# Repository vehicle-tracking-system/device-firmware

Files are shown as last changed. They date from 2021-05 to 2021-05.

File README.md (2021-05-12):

# Tracker for vehicle tracking system

This repository is part of project for tracking vehicles. Main repository with backend server can be
found [here](https://gitlab.fit.cvut.cz/jehlima2/vehicle-tracking-system).

## Configuration

Whole configuration is located in `Constants.h` header file. Default configuration should look like:

```cpp
const int MPU_ADDR = 0x69;
static const int MOVEMENT_THRESHOLD = 3000;

static const int POWER_PIN = 5;

static const int RED_LED_PIN = 26;
static const int GREEN_LED_PIN = 25;

static const int POSITION_FREQUENCE = 3000; // ms
static const int POSITIONS_IN_REPORT = 5;
static const int REPORT_FREQUENCE = POSITIONS_IN_REPORT * POSITION_FREQUENCE; // ms

static char WIFI_SSID[] = "tracker";
static char WIFI_PASSWORD[] = "12345678";

static char STATIC_FILES_PREFIX[] = "/w";
static int HTTP_PORT = 80;
static int DNS_PORT = 53;
static char WEBSOCKET_PATH[] = "/ws";

static float MINIMAL_ACCURACY = 3.0;
static float SPEED_LOWER_LIMIT = 3.0;
static float SPEED_UPPER_LIMIT = 200.0;
```

Variable name | Description
--- | --- 
MPU_ADDR | I2C address of accelerometer
POWER_PIN | ESP32 pin that is connected to power pin on WARCAR module
RED_LED_PIN | Pin that is connected to red (part of) LED
GREEN_LED_PIN | Pin that is connected to green (part of) LED
POSITION_FREQUENCE | sampling frequency of actual vehicle position
REPORT_FREQUENCE | frequency of sending reports to the MQTT broker
MAX_DISTANCE_BETWEEN_TWO_POSITIONS | positions that are set apart that are more than this threshold (in meters) apart are ignored as invalid
WIFI_SSID | name of the wifi network broadcast by the tracker
WIFI_PASSWORD | password to the wifi network broadcast by the tracker
STATIC_FILES_PREFIX | path to frontend in SPIFFS (other) filesystem
HTTP_PORT | number of port where the web ui will be exposed
WEBSOCKET_PATH | path to endpoint where it will be possible to connect
MINIMAL_ACCURACY | data from GPS with lower accuracy then this threshold will be ignored
SPEED_LOWER_LIMIT | data from GPS with lower speed then this threshold will be ignored
SPEED_UPPER_LIMIT | data from GPS with higher speed then this threshold will be ignored

Variables above allows to modify just technical aspects of tracker. The configuration and pairing with backend is done
by the UI. This is the reason why tracker needs to configure WiFi SSID and password. Connect to WiFi broadcast by
tracker (`WIFI_SSID`). Once you will be connected, you can type `tracker.local` into address line in your browser. User
interface will appear and you'll be prompted to upload configuration file. You can generate a configuration file in the
web administration (more info here: *TO DO*).

## Build

A `PlatformIO` framework is required for the code to work properly!

There is `upload-all.sh` build script that compile whole code and uploads it to ESP (ports can be changed
in `platformio.ini`)

## Wiring

Wiring

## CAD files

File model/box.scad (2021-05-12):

DEBUG = false;

board_size = [1.5, 50, 80];
esp_size = [5, 51.8, 28.5];
hole_dia = 2;
inner_box = [45, 55, 82];
fatness = 3.6;
cable_hole_radius = 3.5;
cover_overlay = 10;
bottom_size = inner_box.z / 2 ;
top_size = inner_box.z - bottom_size;
board_thickens = 1.5;
rail_size = board_thickens + 0.2;
rail_thicknes = 1;
round_prec = 40;
led_hole_radius = 5.2;
acc_hole = 2.8;
power_hole_radius = 6;

echo("Box side thicknes ", fatness / 2);

module Board(x, y, z) {
    translate([x, y, z]) union() {
        color("black") cube(board_size);
    }
}

module ESP(x, y, z) {
    translate([x, y, z]) union() {
        color("black") cube(esp_size);
    }
}

module SideRail(x, y, z, length) {
    color("blue") translate([x, y, z]) difference() {
        cube([(rail_size * 2), rail_thicknes, length]);
        translate([rail_size / 2, 0, 0]) {
            cube([rail_size + .01, rail_thicknes + 0.1, length + 0.1]);
        }
    }
}

module BottomRail(x, y, z, length) {
    color("red") translate([x, y, z]) difference() {
        cube([(rail_size * 2), 5, length]);
        translate([rail_size / 2, 0, 0]) {
            cube([rail_size + .01, 5 + 0.1, length + 0.1]);
        }
    }
}

module PowerHole(x, y, z) {
    color("blue") rotate([0, 0, 0]) translate([x, y, z]) {
        cylinder(h = fatness + .02, d = power_hole_radius, $fn = round_prec);
    }
}

module LedHole(x, y, z) {
    color("blue") rotate([90, 0, 90]) translate([y, z, x]) {
        cylinder(h = fatness + .02, d = led_hole_radius, $fn = round_prec);
    }
}


module CableHole(x, y, z) {
    color("blue") rotate([90, 0, 90]) translate([y - fatness, z, x]) {
        translate([- cable_hole_radius / 2, 0, 0]) cube([cable_hole_radius, 100, fatness + .02]);
        cylinder(h = fatness + .02, d = cable_hole_radius, $fn = round_prec);
    }
}

module Bottom(x, y, z) {
    translate([x, y, z]) {
        difference() {
            union() {
                size = [inner_box.x + fatness, inner_box.y + fatness, (bottom_size + (fatness / 2))];
                cube(size);
                echo("Bottom size ", size);
                echo("Bottom overlay thicknes", (fatness / 2) - (fatness / 4));
                color("purple") translate([fatness / 4, fatness / 4, bottom_size + (fatness / 2)]) {
                    size = [inner_box.x + 2 * (fatness / 4), inner_box.y + 2 * (fatness / 4), cover_overlay];
                    echo("Bottom overlay ", size);
                    echo("Top overlay thicknes ", (fatness / 2) - (fatness / 4));
                    cube(size);
                }
            }
            translate([fatness / 2, fatness / 2, fatness / 2]) {
                color("gray") cube([inner_box.x, inner_box.y, bottom_size + 100]);
            }
            CableHole(inner_box.x + fatness / 2 - .01, inner_box.y - 7, 40);
            LedHole(inner_box.x + fatness / 2 - .01, fatness / 2 + inner_box.y / 2, 40);
            PowerHole(fatness / 2 + inner_box.x / 2, fatness / 2 + inner_box.y / 2, 0 - .01);
        }

        color("green") union() {
            translate([((inner_box.x / 5) - rail_size / 2), fatness / 2, fatness]) cube([rail_size * 2, 2.01,
                bottom_size]);
            SideRail(((inner_box.x / 5) - rail_size / 2), ((fatness / 2) + 2) - .01, z + fatness, bottom_size +
                .01)
            ;
            translate([(inner_box.x / 5) - rail_size / 2, (fatness / 2), fatness / 2]) cube([rail_size * 2, 12, 2]);
            rotate([90, 0, 0]) BottomRail(x + (inner_box.x / 5) - rail_size / 2, fatness / 2 - .01 + 2, - (12 + fatness
                / 2)
            , 12);
        }

        color("green") union() {
            translate([((inner_box.x / 5) - rail_size / 2), ((fatness / 2) + inner_box.y) - 3, fatness / 2 + 2])
                cube([rail_size * 2, 3.01, 7]);
            SideRail(((inner_box.x / 5) - rail_size / 2), (fatness / 2 + inner_box.y) - rail_thicknes - 3, z +
                    fatness / 2 + 7 - .01, 2);
            translate([(inner_box.x / 5) - rail_size / 2, (inner_box.y + fatness / 2) - 12, fatness / 2]) cube([
                    rail_size * 2, 12, 2]);
            rotate([90, 0, 0]) BottomRail((inner_box.x / 5) - rail_size / 2, fatness / 2 - .01 + 2, - (inner_box.y +
                    fatness / 2), 12);
        }


        color("pink") translate([(inner_box.x / 10) + 32, .01, fatness / 2]) cube([1, inner_box.y + fatness - .02, 33]);
        translate([inner_box.x - 15, fatness / 2 + 3, fatness / 2 - .01]) {
            roof_len = 22;
            acc_space = (roof_len - 15) / 2;
            echo("Acc space ", acc_space)
            color("white") translate([0, 0, 0]) {
                union() {
                    cylinder(h = 3, d = acc_hole, $fn = round_prec);
                    translate([0, 15, 0]) cylinder(h = 3, d = acc_hole, $fn = round_prec);
                }
            };
        }
        if (DEBUG) Board((inner_box.x / 5), fatness / 2 + 2, fatness / 2);
    }
}

module Cover(x, y, z) {
    translate([x, y, z]) {
        union() {
            difference() {
                size = [inner_box.x + fatness, inner_box.y + fatness, (top_size + (fatness / 2))];
                echo("Top size ", size);
                cube(size);
                translate([fatness / 2, fatness / 2, fatness / 2]) {
                    color("gray") cube([inner_box.x, inner_box.y, top_size + 100]);
                }
                taper_start = top_size - cover_overlay + fatness / 2 + .01;
                echo("Lower edge of taper ", taper_start, " taper height ", top_size - taper_start);
                translate([fatness / 4 - .1, fatness / 4 - .1, taper_start]) {
                    size = [inner_box.x + 2 * (fatness / 4 + .1), inner_box.y + 2 * (fatness / 4 + .1), cover_overlay];
                    echo("Top overlay thicknes ", size);
                    echo("Top overlay thicknes ", (fatness / 2) - (fatness / 4 - .1));
                    color("purple") cube(size);
                }
            }
        }
    }
}


Bottom(0, 0, 0);
Cover(100, 0, 0);
if (DEBUG) ESP(fatness / 2 + 40, (inner_box.y - esp_size.y) / 2, fatness / 2);

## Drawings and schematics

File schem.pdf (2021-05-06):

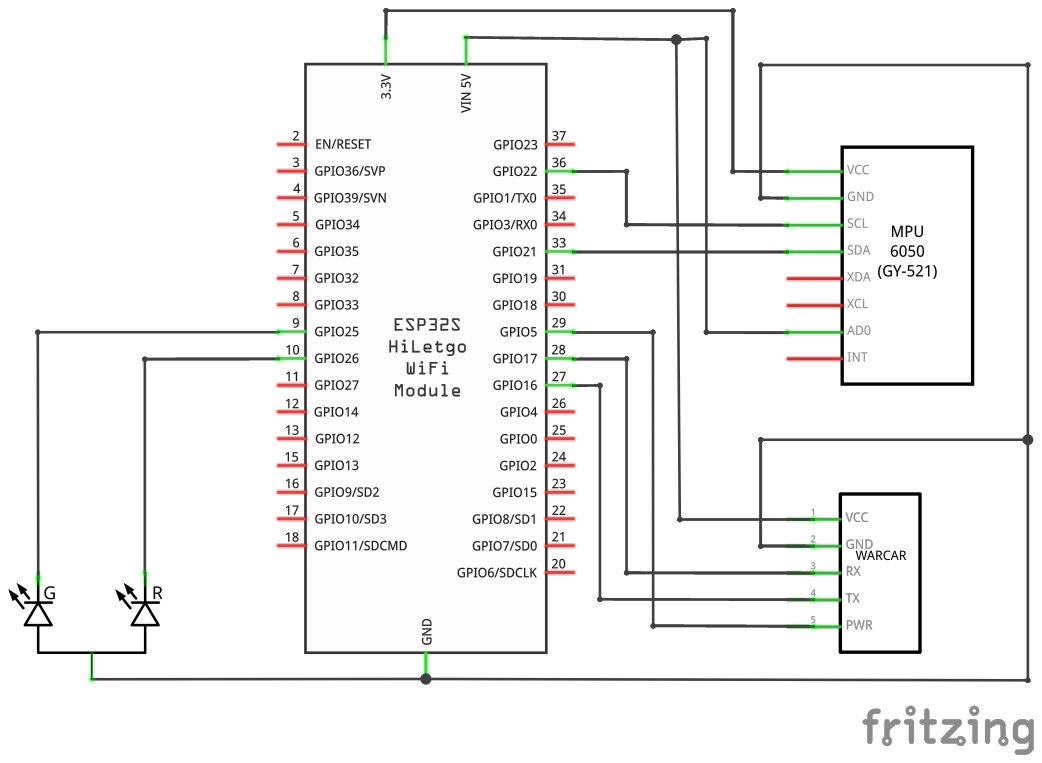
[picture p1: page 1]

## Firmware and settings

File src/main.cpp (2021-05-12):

#include <Arduino.h>

#include <Preferences.h>
#include "Constants.h"
#include <logic/StateManager.h>
#include <logic/GSM.h>
#include <networking/WebServer.h>
#include <networking/AP.h>
#include <networking/WifiClient.h>
#include <logic/LedController.h>
#include <logic/Accelerometer.h>

Preferences preferences;
StateManager stateManager(preferences);
Accelerometer accelerometer(stateManager);
LedController ledController(stateManager);
GSM gsm(stateManager);
WebServer webServer;
JsonConnector jsonConnector;

long counter = 0;

// return in setup function can stop all tasks run from there!
void setup() {
    Serial.begin(115200);
    if (!FileSystem.begin()) {
        ERROR_PRINT("Could not init FS\n", NULL);
    }
    DEBUG_PRINT("Initializing...\n", NULL);
    DEBUG_PRINT("Max distance between two positions is %f\n", MAX_DISTANCE_BETWEEN_TWO_POSITIONS);
    preferences.begin("tracker", false);
    stateManager.begin();

#ifdef USE_ACCELEROMETER
    if (!accelerometer.begin()) {
        ERROR_PRINT("Accelerometer init failed!", NULL);
        stateManager.setError("Accelerometer init failed!");
    }

    DefaultTasker.loopEvery("acc", 50, [] {
        if (!accelerometer.updateAcceleration()) {
            ERROR_PRINT("Update acceleration failed\n", NULL);
        }
//        Serial.printf("%ld,%f\n", counter, stateManager.getAcc());
        counter++;
    });
#endif

    // start webserver
    NetworkTasker.once("ap-server", [] {
#ifdef WIFI_MODE
        WifiClient::begin(WIFI_MODE_SSID, WIFI_MODE_PASS);
#else
        String ssid = WIFI_SSID + WiFi.macAddress();
        DEBUG_PRINT("SSID: %s\n", ssid.c_str());
        AP::begin(ssid.c_str(), WIFI_PASSWORD);
#endif
        webServer.begin(jsonConnector);
    });

#ifndef WIFI_MODE
    // turn off wifi AP and webserver after timeout
    NetworkTasker.once("ap-off", [] {
#ifdef AP_AUTO_OFF
        DEBUG_PRINT("Registering promise to turn off AP...\n", NULL);
        Tasker::sleep(120000);
        DEBUG_PRINT("Turning off AP...\n", NULL);
        AP::stop();
        webServer.stop();
#endif
    });
#endif


    jsonConnector.subscribe([](const JsonDocument &json) {
        DEBUG_PRINT("Configuration JSON received\n", NULL);
        if (json["type"].as<String>() == "file") {
            preferences.putString("token", json["token"].as<char *>());
            preferences.putLong("vehicleId", json["vehicleId"].as<long>());
            preferences.putString("mqttHost", json["mqttHost"].as<String>());
            preferences.putString("mqttTopic", json["mqttTopic"].as<String>());
            preferences.putInt("mqttPort", json["mqttPort"].as<int>());
            preferences.putString("mqttUsername", json["mqttUsername"].as<String>());
            preferences.putString("mqttPassword", json["mqttPassword"].as<String>());
        }
        if (json["type"].as<String>() == "form") {
            preferences.putString("apnHost", json["apnHost"].as<String>());
            preferences.putString("apnUser", json["apnUser"].as<String>());
            preferences.putString("apnPass", json["apnPass"].as<String>());
        }
        stateManager.setTextState("Configuration updated...");
    });

    NetworkTasker.loopEvery("state", 100, [] {
        if (stateManager.stateToSend()) {
            DynamicJsonDocument doc(2048);
            doc["state"] = stateManager.textState() + " " + stateManager.getAcc();
            doc["new"] = stateManager.stateToSend();
            doc["latitude"] = stateManager.lat();
            doc["longitude"] = stateManager.lng();
            doc["speed"] = stateManager.speed();
            doc["isMoving"] = stateManager.moving();
            jsonConnector.send(doc);
        }
    });

    if (!gsm.begin()) {
        ERROR_PRINT("GSM initialization failed! Check wiring and reset.\n", NULL);
        return;
    }

    DEBUG_PRINT("Starting the app...\n", NULL);

    // read new position to buffer from GPS
    DefaultTasker.loopEvery("get-position", POSITION_FREQUENCE, [] {
        gsm.enqueueNewPosition();
    });

    // send report with positions to MQTT broker
    DefaultTasker.loopEvery("send-report", REPORT_FREQUENCE, [] {
        if (!gsm.sendReport()) {
            ERROR_PRINT("Send report failed!!!\n", NULL);
        }
    });

    DEBUG_PRINT("Startup finished!\n", NULL);

}

void loop() {
    // no op - everything is handled by native tasks through Tasker
}

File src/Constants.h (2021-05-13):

#ifndef TRACKER_CONSTANTS_H
#define TRACKER_CONSTANTS_H

#include <FS.h>
#include <SPIFFS.h>

#include "../lib/Tasker/Tasker.h"

//
// MESSAGE LEVELS
//
#define DEBUG
#define ERROR
////

#define TINY_GSM_MODEM_SIM808
//#define TINY_GSM_DEBUG Serial // UNCOMMENT THIS FOR SHOW DEBUG LOGS IN SERIAL
#define SERIALGSM Serial2

#ifdef DEBUG
#define DEBUG_PRINT(x, ...)  Serial.print("[DBG] "); Serial.printf(x, __VA_ARGS__)
#else
#define DEBUG_PRINT(x, ...)
#endif

#ifdef ERROR
#define ERROR_PRINT(x, ...)  Serial.print("[ERR] "); Serial.printf(x, __VA_ARGS__)
#else
#define ERROR_PRINT(x, ...)
#endif

#define AP_AUTO_OFF
#define USE_ACCELEROMETER // IF DEFINED, TRACKER RECOGNIZE MOVEMENT USING ACCELEROMETER
//#define WIFI_MODE // IF DEFINED, TRACKER CONNECT YOURSELF TO WIFI INSTEAD CREATING AP

static const char WIFI_MODE_SSID[] = "";
static const char WIFI_MODE_PASS[] = "";

static const int MPU_ADDR = 0x69;
static const int MOVEMENT_THRESHOLD = 3000;

static const int POWER_PIN = 5;

static const int RED_LED_PIN = 26;
static const int GREEN_LED_PIN = 25;

static const int POSITION_FREQUENCE = 3000; // ms
static const int POSITIONS_IN_REPORT = 5;
static const int REPORT_FREQUENCE = POSITIONS_IN_REPORT * POSITION_FREQUENCE; // ms

static const double MAX_DISTANCE_BETWEEN_TWO_POSITIONS = round(200 / 3.6) * POSITIONS_IN_REPORT;

static const char WIFI_SSID[] = "tracker";
static const char WIFI_PASSWORD[] = "12345678";

static const char STATIC_FILES_PREFIX[] = "/w";
static const int HTTP_PORT = 80;
static const int DNS_PORT = 53;
static const char WEBSOCKET_PATH[] = "/ws";

static const float MINIMAL_ACCURACY = 3.0;
static const float SPEED_LOWER_LIMIT = 5.0;
static const float SPEED_UPPER_LIMIT = 200.0;

#define FileSystem SPIFFS

#endif //TRACKER_CONSTANTS_H

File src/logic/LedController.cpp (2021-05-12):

#include "LedController.h"

LedController::LedController(StateManager &stateManager) {
    pinMode(RED_LED_PIN, OUTPUT);
    pinMode(GREEN_LED_PIN, OUTPUT);
    this->stateManager = &stateManager;
    registerBlinkingRoutine();
}

void LedController::blinkHelper(Color color, int cnt, int duration) {
    while (this->blinking) {
        Tasker::yield();
    }
    this->blinking = true;
    int red = LOW, green = LOW;
    switch (color) {
        case RED:
            red = HIGH;
            break;
        case GREEN:
            green = HIGH;
            break;
        case ORANGE:
            red = HIGH;
            green = HIGH;
            break;
        default:
            return;
    }
    digitalWrite(RED_LED_PIN, LOW);
    digitalWrite(GREEN_LED_PIN, LOW);
    digitalWrite(RED_LED_PIN, red);
    digitalWrite(GREEN_LED_PIN, green);
    Tasker::sleep(duration / 2);
    digitalWrite(RED_LED_PIN, LOW);
    digitalWrite(GREEN_LED_PIN, LOW);
    Tasker::sleep(duration / 2);
    this->blinking = false;
}

void LedController::registerBlinkingRoutine() {
    DefaultTasker.loopEvery("blink", 250, [this] {
        if (stateManager->isError()) {
            blinkHelper(RED, 1, 500);
            return;
        }
        if (stateManager->isReconnecting()) {
            blinkHelper(ORANGE, 1, 500);
        }
        if (stateManager->isGpsReconnecting()) {
            blinkHelper(ORANGE, 1, 1500);
        }
    });
}

void LedController::blink(Color color, int cnt) {
    int red = LOW, green = LOW;
    switch (color) {
        case RED:
            red = HIGH;
            break;
        case GREEN:
            green = HIGH;
            break;
        case ORANGE:
            red = HIGH;
            green = HIGH;
            break;
        default:
            return;
    }

    DefaultTasker.once("blink", [red, green, cnt] {
        for (int i = 0; i < cnt; i++) {
            digitalWrite(RED_LED_PIN, LOW);
            digitalWrite(GREEN_LED_PIN, LOW);
            digitalWrite(RED_LED_PIN, red);
            digitalWrite(GREEN_LED_PIN, green);
            Tasker::sleep(250);
            digitalWrite(RED_LED_PIN, LOW);
            digitalWrite(GREEN_LED_PIN, LOW);
            Tasker::sleep(250);
        }
    });
}

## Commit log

2021-04-10 Split communication with GSM module to separated file
    Remove captive portal.
    Basic API for communication with Accelerometer.
    Add comments to main public functions.
2021-05-06 Add scheme of wiring
2021-05-12 Add 3D model of the box
    [box.scad]
